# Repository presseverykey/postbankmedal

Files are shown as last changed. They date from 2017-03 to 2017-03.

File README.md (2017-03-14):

# POST /bank Hackathon Roadshow Medal

This repository contains hardware documentation (Eagle files and PDF) and firmware sources (C) for the medals given to winners at the POST /bank hackathon series 2016/2017 Grand Final.

The actual boards given out differ in two points:
- MCU ground connections (Pins 5 and 41) are missing on the board due to a PCB manufacturing error. They are manually routed using wire.
- Due to a worldwide supply shortage of TBD62083 drivers, the boards are populated with a TBD62003 chip (7 channels instead of 8). The remaining channel is populated with a 2N7000 NMOS on top of the TBD62003.

The board has pads for a resistive and a capacitive touch sensor, however, they are not used in the current firmware.

The firmware is based on the everykey SDK (see https://github.com/presseverykey/everykey-sdk for prerequisites, toolchain setup and more examples). Basically, an ARM GCC cross compiler and a firmware checksum tool is required. The MCU supports flashing via USB mass storage in ROM, so no additional flashing hardware is required. The firmware binary can be just copied over. To enable flashing mode, press the button while inserting the board to a USB port (add 0.5-1mm of cardboard or similar under the PCB for a stable connection). Some OSes will mount the drive directly, some require an additional reset. If required, a MCU reset can be triggered by connecting the corresponding pad of R5 to GND, e.g. using metal tweezers.

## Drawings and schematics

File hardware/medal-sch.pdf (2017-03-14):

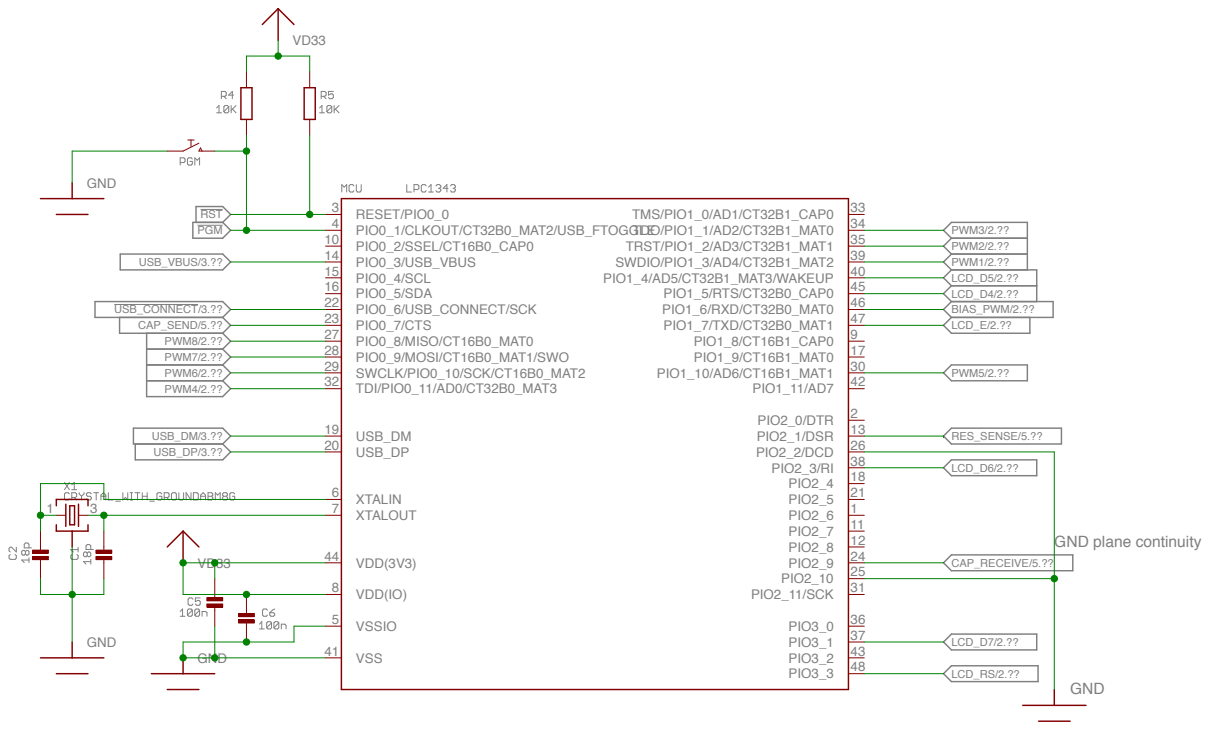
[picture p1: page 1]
GND; PIO2_6; PIO2_0/DTR; RESET/PIO0_0 3 PIO0_1/CLKOUT/CT32B0_MAT2/USB_FTOGGLE 4; VSSIO 5; XTALIN 6 XTALOUT 7; VDD(IO) 8; PIO1_8/CT16B1_CAP0; PIO0_2/SSEL/CT16B0_CAP0 10; PIO2_7; PIO2_8; PIO2_1/DSR; PIO0_3/USB_VBUS 14 PIO0_4/SCL 15 PIO0_5/SDA 16; PIO1_9/CT16B1_MAT0; PIO2_4; USB_DM 19 USB_DP 20; PIO2_5; PIO0_6/USB_CONNECT/SCK 22 PIO0_7/CTS 23; PIO2_9; PIO2_10; PIO2_2/DCD; PIO0_8/MISO/CT16B0_MAT0 27 PIO0_9/MOSI/CT16B0_MAT1/SWO 28; SWCLK/PIO0_10/SCK/CT16B0_MAT2 29; PIO1_10/AD6/CT16B1_MAT1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

GND plane continuity

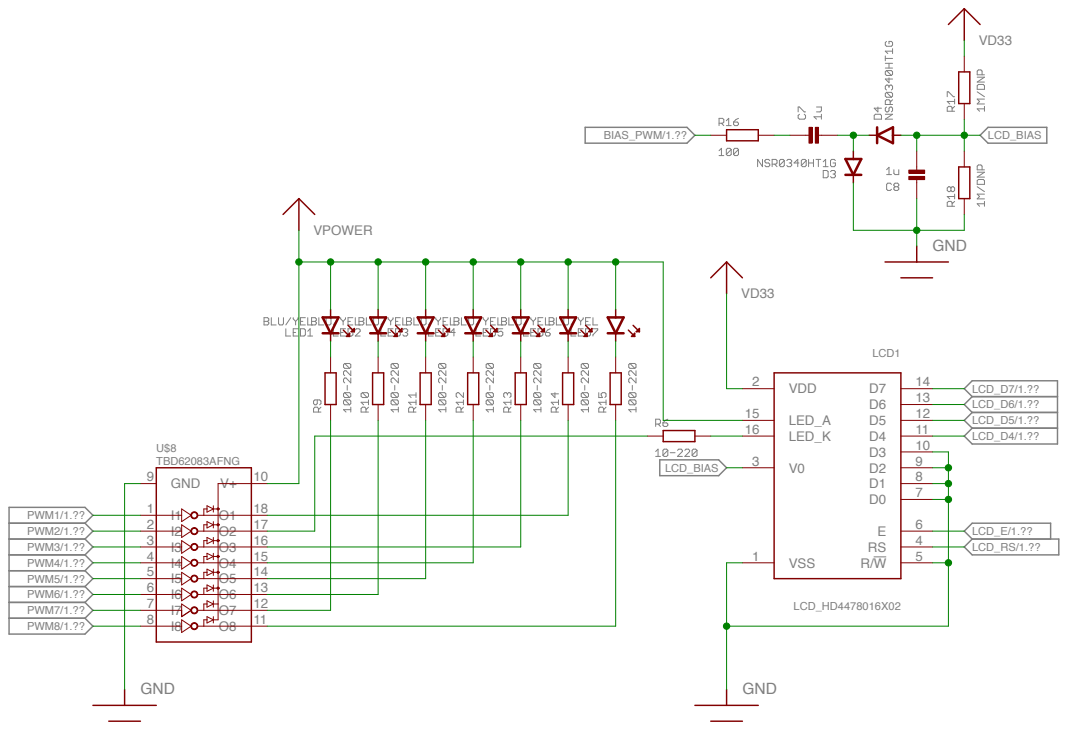
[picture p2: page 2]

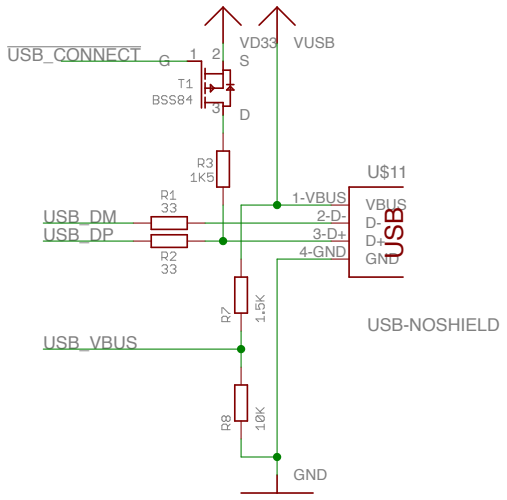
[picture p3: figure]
USB-NOSHIELD; GND; VBUS 1-VBUS D- 2-D- D+ 3-D+ GND 4-GND; VUSB; USB_DM USB_DP; USB_CONNECT; USB_VBUS; USB
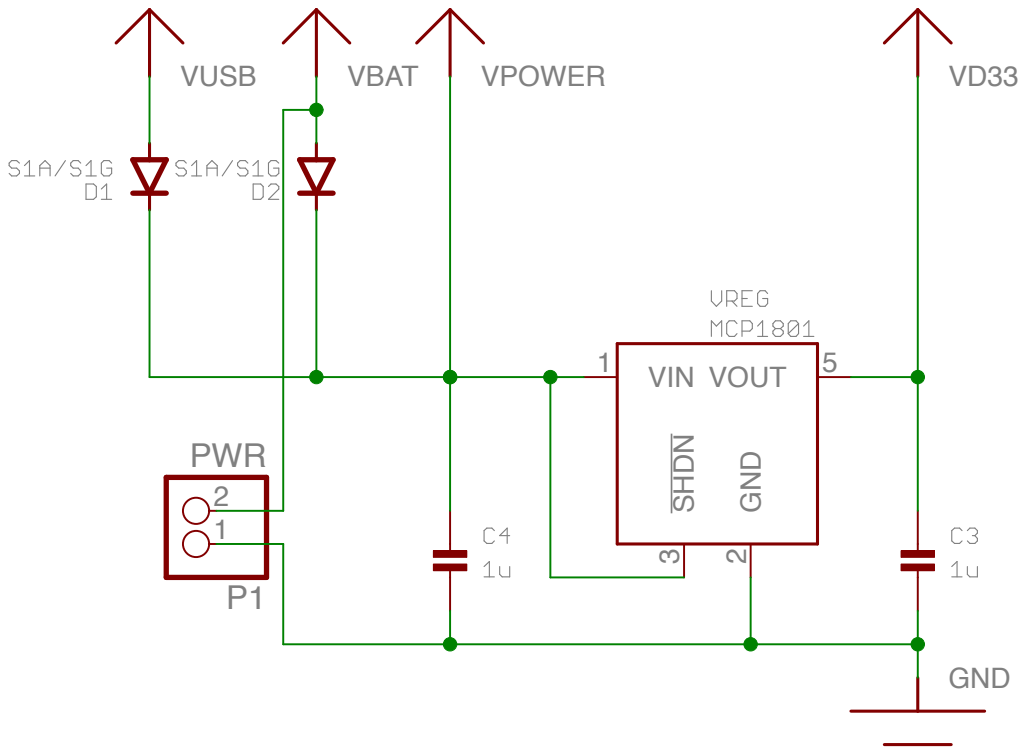
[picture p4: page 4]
PWR; VIN 1; VOUT; 5 GND 2 SHDN 3; GND; VUSB; VBAT; VPOWER

GND

VD33

CAP_SEND/1.??

CAP_RECEIVE/1.??

CAP_PAD

RES_SENSE/1.??

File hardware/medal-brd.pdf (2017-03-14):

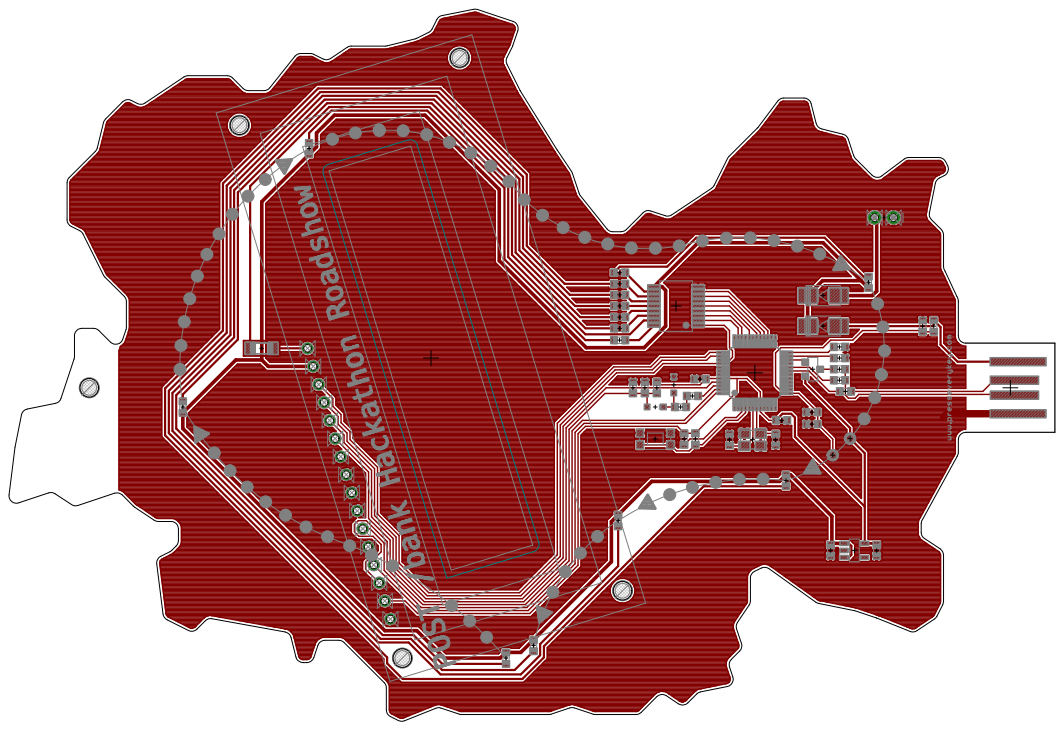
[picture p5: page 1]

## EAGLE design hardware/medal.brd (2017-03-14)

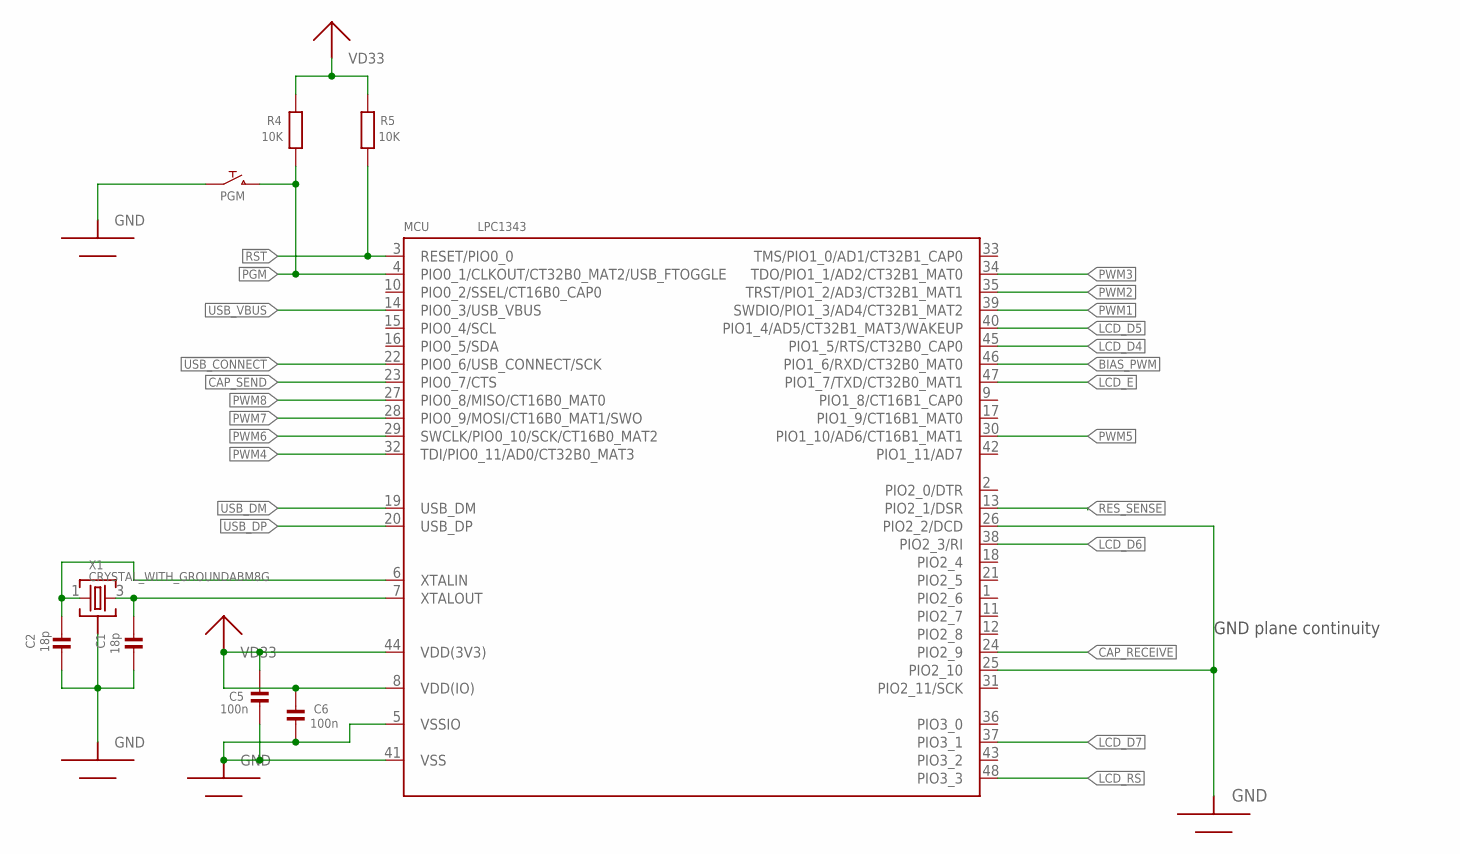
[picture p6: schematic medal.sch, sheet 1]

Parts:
C1, C2: 18p; 0603-NOSILK
C5, C6: 100n; 0603-NOSILK
MCU: LPC1343; QFP48-0.5-NOSILK
PGM: PUSHBUTTONKMR2XX-NOSILK; CK-KMR2-NOSILK
R4, R5: 10K; 0603-NOSILK
X1: CRYSTAL_WITH_GROUNDABM8G; ABM8G

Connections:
!PGM: MCU.4 (PIO0_1/CLKOUT/CT32B0_MAT2/USB_FTOGGLE), PGM.P$3 (2), PGM.P$4 (2), R4.1
!RST: MCU.3 (RESET/PIO0_0), R5.1
!USB_CONNECT: MCU.22 (PIO0_6/USB_CONNECT/SCK); also elsewhere on the board
BIAS_PWM: MCU.46 (PIO1_6/RXD/CT32B0_MAT0); also elsewhere on the board
CAP_RECEIVE: MCU.24 (PIO2_9); also elsewhere on the board
CAP_SEND: MCU.23 (PIO0_7/CTS); also elsewhere on the board
GND: C1.1, C2.1, C5.2, C6.2, MCU.5 (VSSIO), MCU.25 (PIO2_10), MCU.26 (PIO2_2/DCD), MCU.41 (VSS), PGM.P$1 (1), PGM.P$2 (1), X1.2 (GND), X1.4 (GND); also elsewhere on the board
LCD_D4: MCU.45 (PIO1_5/RTS/CT32B0_CAP0); also elsewhere on the board
LCD_D5: MCU.40 (PIO1_4/AD5/CT32B1_MAT3/WAKEUP); also elsewhere on the board
LCD_D6: MCU.38 (PIO2_3/RI); also elsewhere on the board
LCD_D7: MCU.37 (PIO3_1); also elsewhere on the board
LCD_E: MCU.47 (PIO1_7/TXD/CT32B0_MAT1); also elsewhere on the board
LCD_RS: MCU.48 (PIO3_3); also elsewhere on the board
unnamed: C2.2, MCU.6 (XTALIN), X1.1
unnamed: C1.2, MCU.7 (XTALOUT), X1.3 (2)
PWM1: MCU.39 (SWDIO/PIO1_3/AD4/CT32B1_MAT2); also elsewhere on the board
PWM2: MCU.35 (TRST/PIO1_2/AD3/CT32B1_MAT1); also elsewhere on the board
PWM3: MCU.34 (TDO/PIO1_1/AD2/CT32B1_MAT0); also elsewhere on the board
PWM4: MCU.32 (TDI/PIO0_11/AD0/CT32B0_MAT3); also elsewhere on the board
PWM5: MCU.30 (PIO1_10/AD6/CT16B1_MAT1); also elsewhere on the board
PWM6: MCU.29 (SWCLK/PIO0_10/SCK/CT16B0_MAT2); also elsewhere on the board
PWM7: MCU.28 (PIO0_9/MOSI/CT16B0_MAT1/SWO); also elsewhere on the board
PWM8: MCU.27 (PIO0_8/MISO/CT16B0_MAT0); also elsewhere on the board
RES_SENSE: MCU.13 (PIO2_1/DSR); also elsewhere on the board
USB_DM: MCU.19 (USB_DM); also elsewhere on the board
USB_DP: MCU.20 (USB_DP); also elsewhere on the board
USB_VBUS: MCU.14 (PIO0_3/USB_VBUS); also elsewhere on the board
VD33: C5.1, C6.1, MCU.8 (VDD(IO)), MCU.44 (VDD(3V3)), R4.2, R5.2; also elsewhere on the board

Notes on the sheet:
GND plane continuity

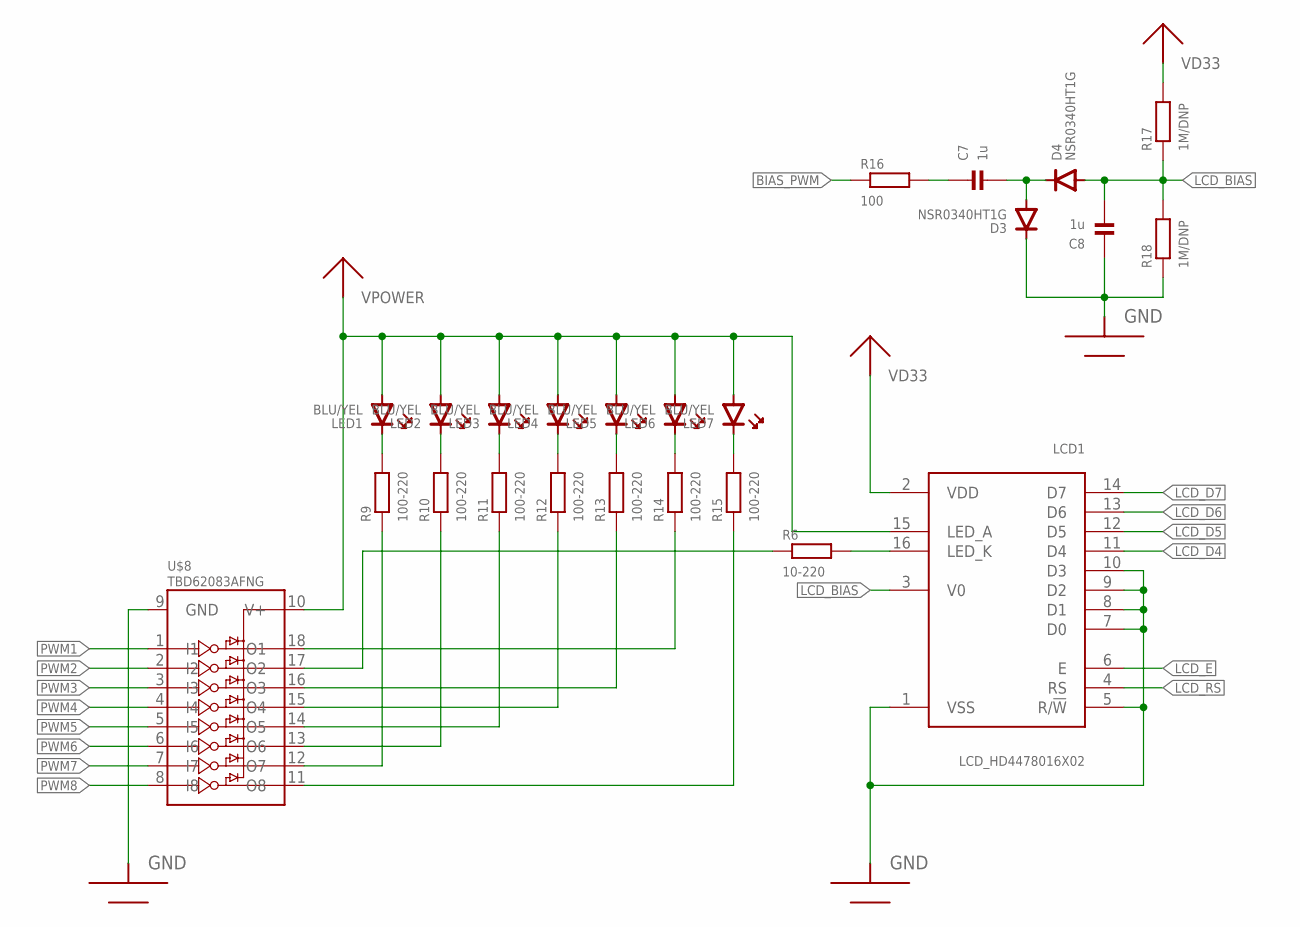
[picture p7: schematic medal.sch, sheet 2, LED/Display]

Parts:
C7, C8: 1u; 0603-NOSILK
D3, D4: NSR0340HT1G; SOD323R-NOPLACE
LCD1: LCD_HD4478016X02; LCD_16X02
LED1, LED2, LED3, LED4, LED5, LED6, LED7: BLU/YEL; 0603_POLAR
R6: 10-220; 1206-NOSILK
R9, R10, R11, R12, R13, R14, R15: 100-220; 0603-NOSILK
R16: 100; 0603-NOSILK
R17, R18: 1M/DNP; 0603-NOSILK
U$8: TBD62083AFNG; SSOP18-4.4-0.65-NOPLACE

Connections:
BIAS_PUMP: C7.2, D3.A (ANODE), D4.K (CATHODE)
BIAS_PWM: R16.1; also elsewhere on the board
BIAS_PWM_LIM: C7.1, R16.2
GND: C8.1, D3.K (CATHODE), LCD1.1 (VSS), LCD1.5 (R/!W), LCD1.7 (D0), LCD1.8 (D1), LCD1.9 (D2), LCD1.10 (D3), R18.1, U$8.9 (GND); also elsewhere on the board
LCD_BIAS: C8.2, D4.A (ANODE), LCD1.3 (V0), R17.1, R18.2
LCD_D4: LCD1.11 (D4); also elsewhere on the board
LCD_D5: LCD1.12 (D5); also elsewhere on the board
LCD_D6: LCD1.13 (D6); also elsewhere on the board
LCD_D7: LCD1.14 (D7); also elsewhere on the board
LCD_E: LCD1.6 (E); also elsewhere on the board
LCD_RS: LCD1.4 (RS); also elsewhere on the board
unnamed: R6.1, U$8.17 (O2)
unnamed: LCD1.16 (LED_K), R6.2
unnamed: R13.1, U$8.16 (O3)
unnamed: R10.1, U$8.13 (O6)
unnamed: LED1.K (CATHODE), R9.2
unnamed: LED2.K (CATHODE), R10.2
unnamed: LED3.K (CATHODE), R11.2
unnamed: LED4.K (CATHODE), R12.2
unnamed: LED5.K (CATHODE), R13.2
unnamed: LED6.K (CATHODE), R14.2
unnamed: LED7.K (CATHODE), R15.2
OC2: R9.1, U$8.12 (O7)
OC4: R11.1, U$8.14 (O5)
OC5: R12.1, U$8.15 (O4)
OC7: R14.1, U$8.18 (O1)
OC8: R15.1, U$8.11 (O8)
PWM1: U$8.1 (I1); also elsewhere on the board
PWM2: U$8.2 (I2); also elsewhere on the board
PWM3: U$8.3 (I3); also elsewhere on the board
PWM4: U$8.4 (I4); also elsewhere on the board
PWM5: U$8.5 (I5); also elsewhere on the board
PWM6: U$8.6 (I6); also elsewhere on the board
PWM7: U$8.7 (I7); also elsewhere on the board
PWM8: U$8.8 (I8); also elsewhere on the board
VD33: LCD1.2 (VDD), R17.2; also elsewhere on the board
VPOWER: LCD1.15 (LED_A), LED1.A (ANODE), LED2.A (ANODE), LED3.A (ANODE), LED4.A (ANODE), LED5.A (ANODE), LED6.A (ANODE), LED7.A (ANODE), U$8.10 (V+); also elsewhere on the board

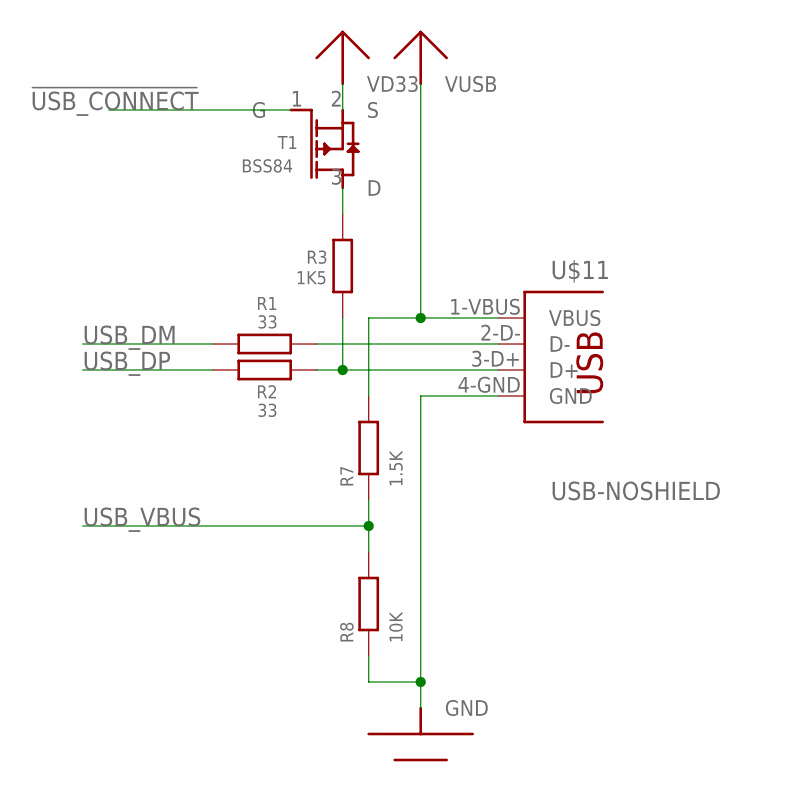
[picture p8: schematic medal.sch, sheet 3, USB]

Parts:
R1, R2: 33; 0603-NOSILK
R3: 1K5; 0603-NOSILK
R7: 1.5K; 0603-NOSILK
R8: 10K; 0603-NOSILK
T1: BSS84; SOT23-NOPLACE
U$11: USB-NOSHIELD; USB-A-PCB

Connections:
!USB_CONNECT: T1.1 (G); also elsewhere on the board
GND: R8.1, U$11.4-GND (GND); also elsewhere on the board
unnamed: R3.1, T1.3 (D)
USB_D+: R2.1, R3.2, U$11.3-D+ (D+)
USB_D-: R1.1, U$11.2-D- (D-)
USB_DM: R1.2; also elsewhere on the board
USB_DP: R2.2; also elsewhere on the board
USB_VBUS: R7.1, R8.2; also elsewhere on the board
VD33: T1.2 (S); also elsewhere on the board
VUSB: R7.2, U$11.1-VBUS (VBUS); also elsewhere on the board

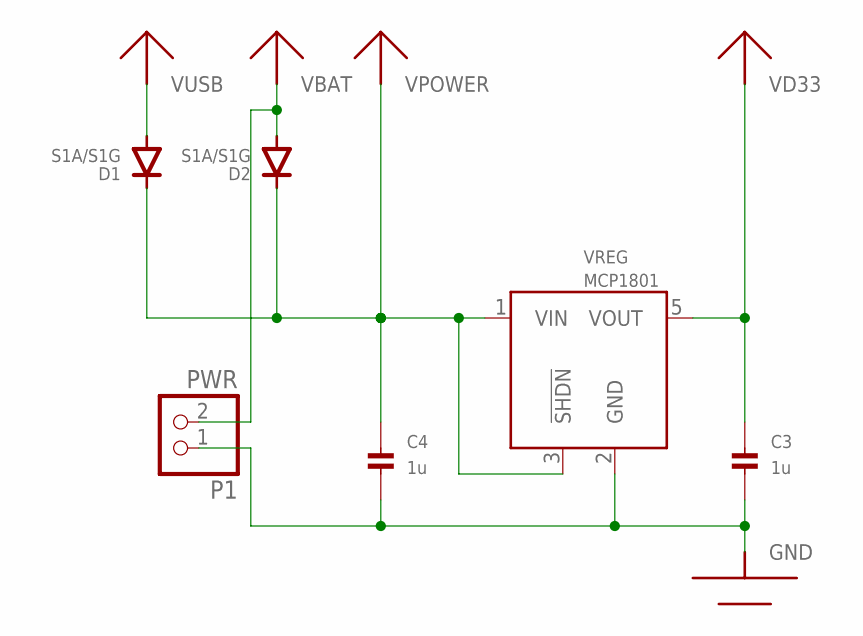
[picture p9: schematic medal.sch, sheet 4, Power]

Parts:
C3, C4: 1u; 0603-NOSILK
D1, D2: S1A/S1G; DSMA-NOPLACE
P1: PWR; 1X02_ROUND
VREG: MCP1801; SOT-23-5-NOSILK

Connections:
GND: C3.2, C4.2, P1.1, VREG.2 (GND); also elsewhere on the board
VBAT: D2.A (ANODE), P1.2
VD33: C3.1, VREG.5 (VOUT); also elsewhere on the board
VPOWER: C4.1, D1.C (CATHODE), D2.C (CATHODE), VREG.1 (VIN), VREG.3 (!SHDN); also elsewhere on the board
VUSB: D1.A (ANODE); also elsewhere on the board

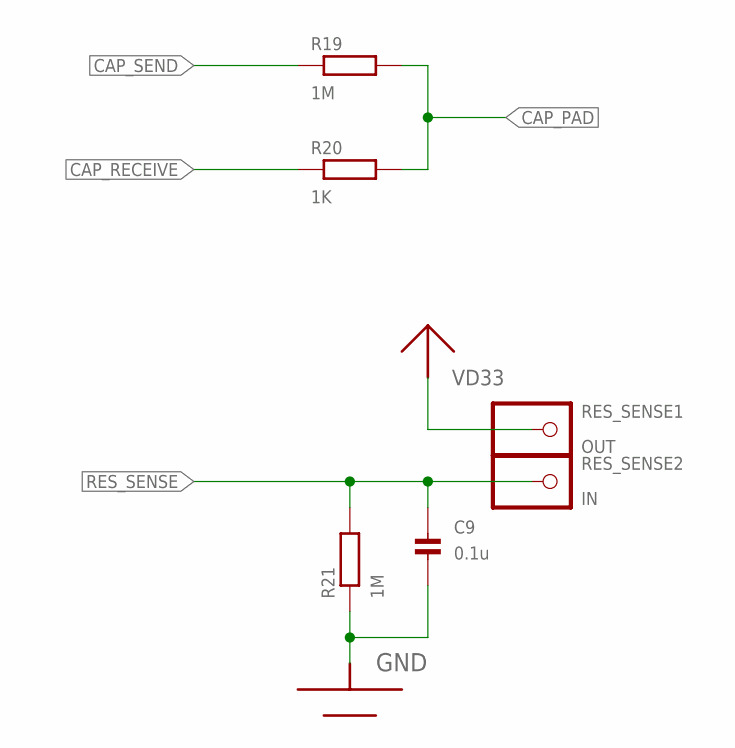
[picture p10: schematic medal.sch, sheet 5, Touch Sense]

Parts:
C9: 0.1u; 0603-NOSILK
R19, R21: 1M; 0603-NOSILK
R20: 1K; 0603-NOSILK
RES_SENSE1: OUT; 1X01_1MM_ROUND
RES_SENSE2: IN; 1X01_1MM_ROUND

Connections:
CAP_PAD: R19.2, R20.2
CAP_RECEIVE: R20.1; also elsewhere on the board
CAP_SEND: R19.1; also elsewhere on the board
GND: C9.2, R21.1; also elsewhere on the board
RES_SENSE: C9.1, R21.2, RES_SENSE2.P$2; also elsewhere on the board
VD33: RES_SENSE1.P$2; also elsewhere on the board

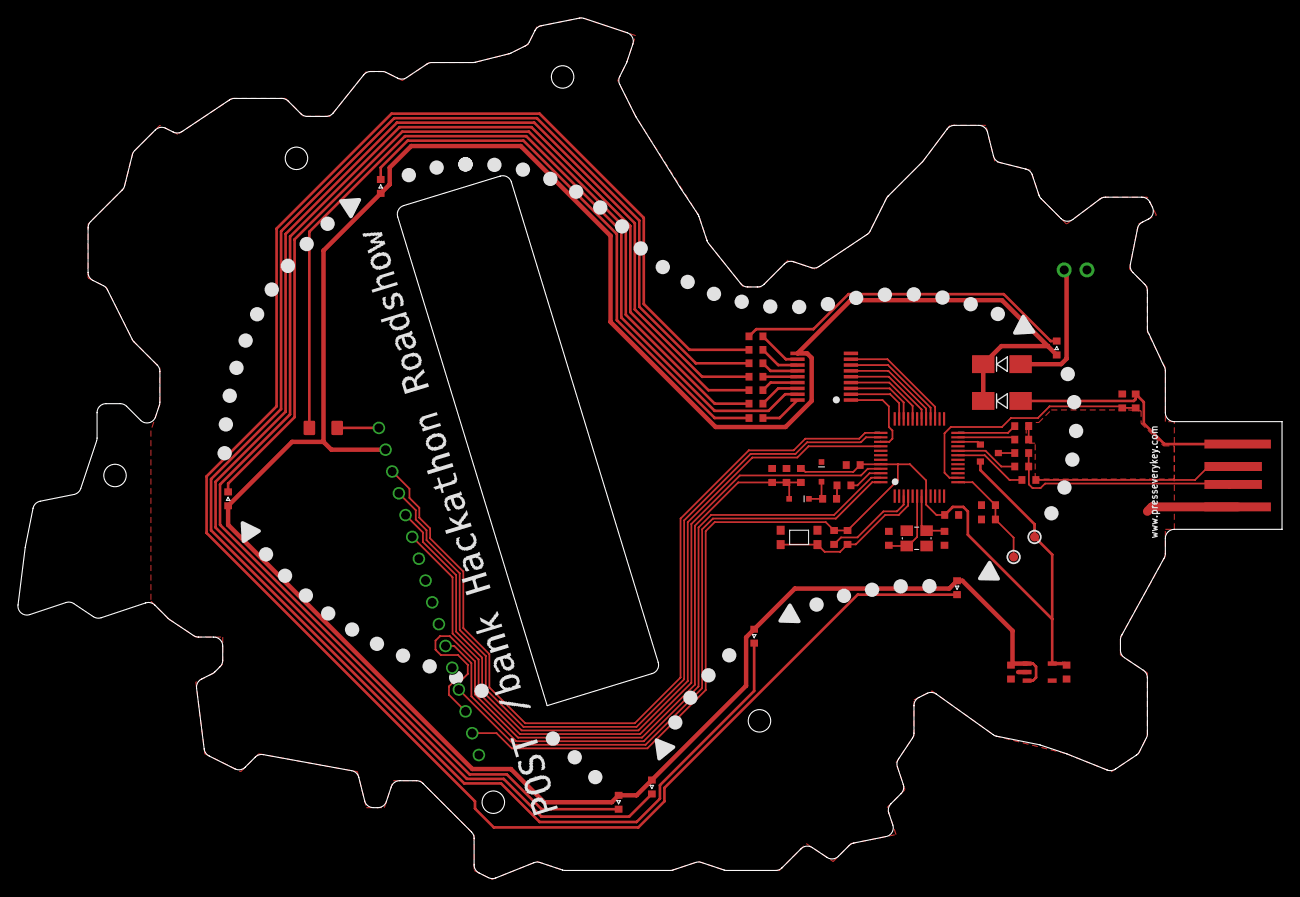
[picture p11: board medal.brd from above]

Board: 2 copper layers, 140.8 x 95.9 mm, 52 parts (0 on the bottom side), 54 nets.

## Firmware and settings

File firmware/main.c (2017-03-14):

#include "everykey/everykey.h"


typedef enum {
    GOTO = 0,        //arg1: LED mask, arg2: target value
    FADE,            //arg1: LED mask, arg2: target value, arg3: speed
    SPARKLE,         //arg1: LED mask
    SETTEXT,         //arg1: row, arg2: text index
    CLEARSCREEN,     //no args
    END,             //no args
    LOOP,            //no args
    TYPESTART,       //no args. Goes to line 1, turns on blinking cursor
    TYPE,            //arg2: char
    TYPEEND          //no args. Turns off blinking cursor
} COMMAND_ID;

typedef struct {
    uint16_t ticks;
    COMMAND_ID command;
    uint16_t arg1;
    uint8_t arg2;
    uint8_t arg3;
} Command;

const Command commands[] = {
    { 0, GOTO, 0b111111111, 0 },
    { 0, CLEARSCREEN, 0, 0, 0 },

    { 128, FADE, 0b000000011, 255, 2 }, //POST /bank fade up
//    {   0, SETTEXT, 0, 0, 0},           
    {   0, TYPESTART, 0, 0, 0 },
    { 200, TYPE, 0, 'P', 0 },
    {  30, TYPE, 0, 'O', 0 },
    {  30, TYPE, 0, 'S', 0 },
    {  30, TYPE, 0, 'T', 0 },
    {  30, TYPE, 0, ' ', 0 },
    {  30, TYPE, 0, '/', 0 },
    {  30, TYPE, 0, 'b', 0 },
    {  30, TYPE, 0, 'a', 0 },
    {  30, TYPE, 0, 'n', 0 },
    {  30, TYPE, 0, 'k', 0 },

    { 200, TYPEEND, 0, 0, 0 },     //blend to Hackathon Roadshow
    {   0, FADE, 0b000000001, 0, 2 },
    { 128, SETTEXT, 0, 1, 0},
    {   0, SETTEXT, 1, 2, 0},
    {   0, FADE, 0b000000001, 255, 2 },

    { 300, FADE, 0b000000011, 0, 2 },   //fade out
    
    { 128, SETTEXT, 0, 3, 0},           //Cologne
    {   0, SETTEXT, 1, 4, 0},
    {   0, FADE, 0b100000011, 255, 5 },
    { 200, FADE, 0b100000011, 0, 1 },

    { 128, SETTEXT, 0, 5, 0},           //Hamburg
    {   0, SETTEXT, 1, 6, 0},
    {   0, FADE, 0b010000011, 255, 5 },
    { 200, FADE, 0b010000011, 0, 1 },

    { 128, SETTEXT, 0, 7, 0},           //Berlin
    {   0, SETTEXT, 1, 8, 0},
    {   0, FADE, 0b001000011, 255, 5 },
    { 200, FADE, 0b001000011, 0, 1 },

    { 128, SETTEXT, 0, 9, 0},           //Munich
    {   0, SETTEXT, 1, 10, 0},
    {   0, FADE, 0b000100011, 255, 5 },
    { 200, FADE, 0b000100011, 0, 1 },

    { 128, SETTEXT, 0, 11, 0},          //Stuttgart
    {   0, SETTEXT, 1, 12, 0},
    {   0, FADE, 0b000010011, 255, 5 },
    { 200, FADE, 0b000010011, 0, 1 },

    { 128, SETTEXT, 0, 13, 0},          //Frankfurt
    {   0, SETTEXT, 1, 14, 0},
    {   0, FADE, 0b000001011, 255, 5 },
    { 200, FADE, 0b000001011, 0, 1 },

    { 128, SETTEXT, 0, 15, 0},          //Bonn
    {   0, SETTEXT, 1, 16, 0},
    {   0, FADE, 0b000000111, 255, 5 },
    { 200, FADE, 0b000000111, 0, 1 },

    { 128, SETTEXT, 0, 17, 0},          //Prize
    {   0, SETTEXT, 1, 18, 0},
    {   0, FADE, 0b000000011, 255, 2 },
    {   0, SPARKLE, 0b111111100, 0, 0 },
    { 200, FADE, 0b000000001, 150, 2},
    { 200, FADE, 0b000000001, 255, 2},
    { 200, FADE, 0b000000001, 150, 2},
    { 200, FADE, 0b000000001, 255, 2},
    { 200, FADE, 0b000000001, 150, 2},
    { 200, FADE, 0b000000001, 255, 2},
    { 200, FADE, 0b000000001, 150, 2},
    { 200, FADE, 0b000000001, 255, 2},
    { 200, FADE, 0b000000001, 150, 2},
    { 200, FADE, 0b000000001, 255, 2},
    { 200, FADE, 0b000000001, 150, 2},
    { 200, FADE, 0b000000001, 255, 2},
    { 200, FADE, 0b000000001, 150, 2},
    { 200, FADE, 0b000000001, 255, 2},
    { 200, FADE, 0b111111111, 0, 2 },

    { 200, LOOP, 0, 0, 0}
};

const char * const strings[] = {
    "POST /bank    ", //0
    "Hackathon     ", //1
    "Roadshow      ", //2
    "K\357ln          ", //3
    "3.-5.6.16     ", //4
    "Hamburg       ", //5
    "21.7.16       ", //6
    "Berlin        ", //7
    "30.9.-2.10.16 ", //8
    "M\365nchen       ", //9
    "20.10.16      ", //10
    "Stuttgart     ", //11
    "25.-27.11.16  ", //12
    "Frankfurt a.M.", //13
    "19.1.17       ", //14
    "Bonn          ", //15
    "17.3.17       ", //16
    "hack.institute", //17
    "sagt DANKE!   "  //18
};

const uint16_t gamma[] = {
    0,66,67,69,71,73,75,77,79,81,84,86,88,91,93,96,
    99,101,104,107,110,113,116,119,122,126,129,133,137,140,144,148,
    152,156,161,165,170,174,179,184,189,194,200,205,211,217,223,229,
    235,242,248,255,262,270,277,285,292,301,309,317,326,335,344,354,
    364,374,384,394,405,417,428,440,452,464,477,490,504,518,532,547,
    562,577,593,609,626,644,661,680,698,718,737,758,779,800,822,845,
    868,892,917,942,968,994,1022,1050,1079,1109,1139,1171,1203,1236,1270,1305,
    1341,1378,1416,1455,1495,1537,1579,1622,1667,1713,1760,1809,1859,1910,1963,2017,
    2072,2130,2188,2249,2311,2374,2440,2507,2576,2647,2720,2795,2872,2951,3033,3116,
    3202,3290,3381,3474,3570,3669,3770,3874,3980,4090,4203,4319,4438,4560,4686,4815,
    4948,5084,5224,5368,5516,5669,5825,5985,6150,6320,6494,6673,6857,7046,7241,7440,
    7645,7856,8073,8295,8524,8759,9000,9249,9504,9766,10035,10311,10596,10888,11188,11496,
    11813,12139,12474,12818,13171,13534,13907,14291,14685,15089,15505,15933,16372,16823,17287,17764,
    18254,18757,19274,19805,20351,20912,21489,22081,22690,23316,23958,24619,25298,25995,26712,27448,
    28205,28983,29782,30603,31446,32313,33204,34119,35060,36027,37020,38040,39089,40167,41274,42412,
    43581,44783,46018,47286,48590,49929,51306,52720,54174,55667,57202,58779,60400,62065,63776,65534
};


#define BUTTON_PORT 0
#define BUTTON_PIN 1

#define CT16B0_RESET_MAT 3
#define CT16B1_RESET_MAT 0
#define CT32B0_RESET_MAT 1
#define CT32B1_RESET_MAT 3

#define TIMER_PRESCALE 0
#define TIMER_PERIOD 65535
#define BIAS_VAL 2000

#define PWM1_PORT 0 //Circuit PWM4 - LED4 - Cologne
#define PWM1_PIN 11
#define PWM1_TIMER CT32B0
#define PWM1_MAT 3

#define PWM2_PORT 1 //Circuit PWM3 - LED5 - Hamburg
#define PWM2_PIN 1
#define PWM2_TIMER CT32B1
#define PWM2_MAT 0

#define PWM3_PORT 1 //Circuit PWM1 - LED6 - Berlin
#define PWM3_PIN 3
#define PWM3_TIMER CT32B1
#define PWM3_MAT 2

#define PWM4_PORT 0 //Circuit PWM8 - LED7 - Munich
#define PWM4_PIN 8
#define PWM4_TIMER CT16B0
#define PWM4_MAT 0

#define PWM5_PORT 0 //Circuit PWM7 - LED1 - Stuttgart
#define PWM5_PIN 9
#define PWM5_TIMER CT16B0
#define PWM5_MAT 1

#define PWM6_PORT 0 //Circuit PWM6 - LED2 - Frankfurt
#define PWM6_PIN 10
#define PWM6_TIMER CT16B0
#define PWM6_MAT 2

#define PWM7_PORT 1 //Circuit PWM5 - LED3 - Bonn
#define PWM7_PIN 10
#define PWM7_TIMER CT16B1
#define PWM7_MAT 1

#define BIASPWM_PORT 1
#define BIASPWM_PIN 6
#define BIASPWM_TIMER CT32B0
#define BIASPWM_MAT 0

#define LCDPWM_PORT 1
#define LCDPWM_PIN 2
#define LCDPWM_TIMER CT32B1
#define LCDPWM_MAT 1

#define LCD_RS_PORT 3
#define LCD_RS_PIN 3

#define LCD_E_PORT 1
#define LCD_E_PIN 7

#define LCD_D4_PORT 1
#define LCD_D4_PIN 5

#define LCD_D5_PORT 1
#define LCD_D5_PIN 4

#define LCD_D6_PORT 2
#define LCD_D6_PIN 3

#define LCD_D7_PORT 3
#define LCD_D7_PIN 1


/*   
 HD44780 write commands:
 
 D7  6  5  4  3  2  1  0
 
 0  0  0  0  0  0  0  1 : Clear display, home cursor
 0  0  0  0  0  0  1  - : Return cursor to home
 0  0  0  0  0  1  ID S : Set cursor move direction. ID=1: Increment cursor after write, S=Shift after write
 0  0  0  0  1  D  C  B : Enable display/cursor. D=1: Display on, C=1: Cursor on, B=1: Blink on
 0  0  0  1  SC RL -  - : Move cursor/shift display: SC=1:Shift display on, RL=1:shift right
 0  0  1  DL N  F  -  - : Set interface: DL=1:8 Bit (4 otherwise), N=1:2 lines (1 otherwise), F=1:5x10 font (5x7 otherwise)
 0  1  A  A  A  A  A  A : Move cursor to CGRAM. A:address
 1  A  A  A  A  A  A  A : Move cursor to display. A:address
 
 */

/** Simple busy wait. Should not be used from outside. Probably waits too long... */
void LCD_Wait_US(uint32_t us) {
    volatile uint32_t i = 30 * us;
    while (i > 0) i--;
}

/** writes one nibble. Should not be used from outside */
void LCD_Write4(bool rs, uint8_t value) {
    every_gpio_write(LCD_RS_PORT, LCD_RS_PIN, rs);
    every_gpio_write(LCD_D7_PORT, LCD_D7_PIN, value & 8);
    every_gpio_write(LCD_D6_PORT, LCD_D6_PIN, value & 4);
    every_gpio_write(LCD_D5_PORT, LCD_D5_PIN, value & 2);
    every_gpio_write(LCD_D4_PORT, LCD_D4_PIN, value & 1);
    
    every_gpio_write(LCD_E_PORT, LCD_E_PIN, true);
    LCD_Wait_US(1);
    
    every_gpio_write(LCD_E_PORT, LCD_E_PIN, false);
    LCD_Wait_US(1);
}

/** writes one byte using a 4 bit interface. Should not be used from outside */
void LCD_Write8(bool rs, uint8_t value) {
    LCD_Write4(rs, (value >> 4) & 0x0f);
    LCD_Write4(rs, value & 0x0f);
    LCD_Wait_US(60);
    if (!rs) LCD_Wait_US(2000);

}

/** writes a string onto screen, starting at the current cursor position. Chars 8-15 are also mapped to custom chars
 so that custom char 0 can be used even though 0 is end of string. */
void LCD_WriteString(const uint8_t* string) {
    int i=0;
    while (true) {
        uint8_t ch = string[i++];
        if (!ch) break;
        if ((ch >= 0x08) && (ch < 0x10)) ch-=8;
        LCD_Write8(true, ch);
    }
}

/** Clears the screen and homes the cursor */
void LCD_ClearScreen() {
    LCD_Write8(false, 0x01);    //clear screen, home cursor
}

/** Moves the cursor to the top left position. In contrast to GotoPosition, shifting is also reset. */
void LCD_Home() {
    LCD_Write8(false, 0x02);    //home cursor, reset shifts
}

/** turns the display and cursor features on or off. Does not modify memory contents. */
void LCD_EnableDisplay(bool screenOn, bool cursorOn, bool blinkOn) {
    LCD_Write8(false, 0x08 | (screenOn ? 0x04 : 0x00) | (cursorOn ? 0x02 : 0x00) | (blinkOn ? 0x01 : 0x00));    //display, cursor, blink on
}

/** sets the cursor to a given position. Note that this does not reflect funny memory maps found in some display configurations. 
 Two row displays should be fine */
void LCD_GotoPosition(uint8_t row, uint8_t col) {
    LCD_Write8(false, 0x80 | (row << 6) | col);
}

/** Defines a custom character (codes 0-7).
 Bitmap should be 8 bytes (rows, pixels right-aligned) even though sometimes only 7 are shown.
 Function will reset cursor position to home. */
void LCD_DefineChar(uint8_t charCode, const uint8_t bitmap[]) {
    LCD_Write8(false, 0x40 | (charCode << 3));
    int i;
    for (i=0; i<8; i++) {
        LCD_Write8(true, bitmap[i]);
    }
    LCD_Home();
}

/** initializes the pins and configures the display to a usable state */
void LCD_Init() {
    EVERY_GPIO_SET_FUNCTION(LCD_RS_PORT, LCD_RS_PIN, PIO, ADMODE_DIGITAL);
    every_gpio_set_dir(LCD_RS_PORT, LCD_RS_PIN, OUTPUT);
    every_gpio_write(LCD_RS_PORT, LCD_RS_PIN, 0);  //RS: 0 = command, 1 = data

    EVERY_GPIO_SET_FUNCTION(LCD_E_PORT, LCD_E_PIN, PIO, ADMODE_DIGITAL);
    every_gpio_set_dir(LCD_E_PORT, LCD_E_PIN, OUTPUT);
    every_gpio_write(LCD_E_PORT, LCD_E_PIN, 0);  //E: falling edge triggers transfer

    EVERY_GPIO_SET_FUNCTION(LCD_D4_PORT, LCD_D4_PIN, PIO, IOCON_IO_ADMODE_DIGITAL);
    every_gpio_set_dir(LCD_D4_PORT, LCD_D4_PIN, OUTPUT);
    every_gpio_write(LCD_D4_PORT, LCD_D4_PIN, 0);

    EVERY_GPIO_SET_FUNCTION(LCD_D5_PORT, LCD_D5_PIN, PIO, IOCON_IO_ADMODE_DIGITAL);
    every_gpio_set_dir(LCD_D5_PORT, LCD_D5_PIN, OUTPUT);
    every_gpio_write(LCD_D5_PORT, LCD_D5_PIN, 0);

    EVERY_GPIO_SET_FUNCTION(LCD_D6_PORT, LCD_D6_PIN, PIO, IOCON_IO_ADMODE_DIGITAL);
    every_gpio_set_dir(LCD_D6_PORT, LCD_D6_PIN, OUTPUT);
    every_gpio_write(LCD_D6_PORT, LCD_D6_PIN, 0);

    EVERY_GPIO_SET_FUNCTION(LCD_D7_PORT, LCD_D7_PIN, PIO, IOCON_IO_ADMODE_DIGITAL);
    every_gpio_set_dir(LCD_D7_PORT, LCD_D7_PIN, OUTPUT);
    every_gpio_write(LCD_D7_PORT, LCD_D7_PIN, 0);

    LCD_Wait_US(40000);
    
    LCD_Write4(false, 0x02);
    LCD_Wait_US(5000);

    LCD_Write8(false, 0x28);    //function set: 4 bit, 2 lines, 5x7 font
    LCD_Write8(false, 0x06);    //entry mode: Move cursor
    LCD_EnableDisplay(true, false, false);
    LCD_ClearScreen();
}

uint16_t timerValues[9];    //LED1-7, LCD BG, LCD BIAS

void PWM_UpdateValues() {
    Timer_SetMatchValue(PWM1_TIMER, PWM1_MAT, timerValues[0]);
    Timer_SetMatchValue(PWM2_TIMER, PWM2_MAT, timerValues[1]);
    Timer_SetMatchValue(PWM3_TIMER, PWM3_MAT, timerValues[2]);
    Timer_SetMatchValue(PWM4_TIMER, PWM4_MAT, timerValues[3]);
    Timer_SetMatchValue(PWM5_TIMER, PWM5_MAT, timerValues[4]);
    Timer_SetMatchValue(PWM6_TIMER, PWM6_MAT, timerValues[5]);
    Timer_SetMatchValue(PWM7_TIMER, PWM7_MAT, timerValues[6]);
    Timer_SetMatchValue(LCDPWM_TIMER, LCDPWM_MAT, timerValues[7]);
    Timer_SetMatchValue(BIASPWM_TIMER, BIASPWM_MAT, timerValues[8]);
}

void PWM_Init() {
    Timer_Enable(CT16B0, true);
    Timer_Enable(CT16B1, true);
    Timer_Enable(CT32B0, true);
    Timer_Enable(CT32B1, true);
    Timer_SetPrescale(CT16B0, TIMER_PRESCALE);
    Timer_SetPrescale(CT16B1, TIMER_PRESCALE);
    Timer_SetPrescale(CT32B0, TIMER_PRESCALE);
    Timer_SetPrescale(CT32B1, TIMER_PRESCALE);
    Timer_SetMatchValue(CT16B0, CT16B0_RESET_MAT, TIMER_PERIOD);
    Timer_SetMatchValue(CT16B1, CT16B1_RESET_MAT, TIMER_PERIOD);
    Timer_SetMatchValue(CT32B0, CT32B0_RESET_MAT, TIMER_PERIOD);
    Timer_SetMatchValue(CT32B1, CT32B1_RESET_MAT, TIMER_PERIOD);
    Timer_SetMatchBehaviour(CT16B0, CT16B0_RESET_MAT, TIMER_MATCH_RESET);
    Timer_SetMatchBehaviour(CT16B1, CT16B1_RESET_MAT, TIMER_MATCH_RESET);
    Timer_SetMatchBehaviour(CT32B0, CT32B0_RESET_MAT, TIMER_MATCH_RESET);
    Timer_SetMatchBehaviour(CT32B1, CT32B1_RESET_MAT, TIMER_MATCH_RESET);

    Timer_EnablePWM(PWM1_TIMER, PWM1_MAT, true);
    Timer_EnablePWM(PWM2_TIMER, PWM2_MAT, true);
    Timer_EnablePWM(PWM3_TIMER, PWM3_MAT, true);
    Timer_EnablePWM(PWM4_TIMER, PWM4_MAT, true);
    Timer_EnablePWM(PWM5_TIMER, PWM5_MAT, true);
    Timer_EnablePWM(PWM6_TIMER, PWM6_MAT, true);
    Timer_EnablePWM(PWM7_TIMER, PWM7_MAT, true);
    Timer_EnablePWM(LCDPWM_TIMER, LCDPWM_MAT, true);
    Timer_EnablePWM(BIASPWM_TIMER, BIASPWM_MAT, true);

    EVERY_GPIO_SET_FUNCTION(PWM1_PORT, PWM1_PIN, TMR, ADMODE_DIGITAL);
    EVERY_GPIO_SET_FUNCTION(PWM2_PORT, PWM2_PIN, TMR, ADMODE_DIGITAL);
    EVERY_GPIO_SET_FUNCTION(PWM3_PORT, PWM3_PIN, TMR, ADMODE_DIGITAL);
    EVERY_GPIO_SET_FUNCTION(PWM4_PORT, PWM4_PIN, TMR, ADMODE_DIGITAL);
    EVERY_GPIO_SET_FUNCTION(PWM5_PORT, PWM5_PIN, TMR, ADMODE_DIGITAL);
    EVERY_GPIO_SET_FUNCTION(PWM6_PORT, PWM6_PIN, TMR, ADMODE_DIGITAL);
    EVERY_GPIO_SET_FUNCTION(PWM7_PORT, PWM7_PIN, TMR, ADMODE_DIGITAL);
    EVERY_GPIO_SET_FUNCTION(LCDPWM_PORT, LCDPWM_PIN, TMR, ADMODE_DIGITAL);
    EVERY_GPIO_SET_FUNCTION(BIASPWM_PORT, BIASPWM_PIN, TMR, ADMODE_DIGITAL);

    for (int i=0; i<8; i++) {
        timerValues[i] = 65535;
    }
    timerValues[8] = BIAS_VAL;
    PWM_UpdateValues();

    Timer_Reset(CT16B0);
    Timer_Reset(CT16B1);
    Timer_Reset(CT32B0);
    Timer_Reset(CT32B1);
    Timer_Start(CT16B0);
    Timer_Start(CT16B1);
    Timer_Start(CT32B0);
    Timer_Start(CT32B1);
}

void main(void) {

    EVERY_GPIO_SET_FUNCTION(BUTTON_PORT, BUTTON_PIN, PIO, ADMODE_DIGITAL);
    every_gpio_set_dir(BUTTON_PORT, BUTTON_PIN, INPUT);
    EVERY_GPIO_SET_PULL(BUTTON_PORT,BUTTON_PIN, PULL_UP);

    PWM_Init();
    LCD_Init();
    
    const uint8_t char0[] = {0x10,0x10,0x10,0x10,0x10,0x10,0x10,0x10};
    const uint8_t char1[] = {0x18,0x18,0x18,0x18,0x18,0x18,0x18,0x18};
    const uint8_t char2[] = {0x1c,0x1c,0x1c,0x1c,0x1c,0x1c,0x1c,0x1c};
    const uint8_t char3[] = {0x1e,0x1e,0x1e,0x1e,0x1e,0x1e,0x1e,0x1e};
    const uint8_t char4[] = {0x1f,0x1f,0x1f,0x1f,0x1f,0x1f,0x1f,0x1f};
    LCD_DefineChar(0,char0);
    LCD_DefineChar(1,char1);
    LCD_DefineChar(2,char2);
    LCD_DefineChar(3,char3);
    LCD_DefineChar(4,char4);

    SYSCON_StartSystick_10ms();
}

uint32_t ticks = 0;
uint32_t totalTicks = 0;
uint32_t commandIdx = 0;
bool running = true;
uint8_t ledValue[9];
uint8_t ledTarget[9];
uint8_t ledSpeed[9];    //ff = sparkle

void parseCommand() {
    if (!running) { //not running: check start condition
        if (!every_gpio_read(BUTTON_PORT, BUTTON_PIN)) {
            ticks = 0;
            commandIdx = 0;
            running = true;
        } else {
            return;
        }
    }
    ticks++;
    totalTicks++;
    uint16_t nextTick = commands[commandIdx].ticks;
    while (ticks >= nextTick) {
        COMMAND_ID cmd = commands[commandIdx].command;
        uint16_t arg1 = commands[commandIdx].arg1;
        uint8_t arg2 = commands[commandIdx].arg2;
        uint8_t arg3 = commands[commandIdx].arg3;
        switch (cmd) {
            case GOTO:
                for (int i=0; i<9; i++) {
                    if (arg1 & (0x100 >> i)) {
                        ledValue[i] = arg2;
                        ledTarget[i] = arg2;
                        ledSpeed[i] = 0;
                    }
                }
                break;
            case FADE:
                for (int i=0; i<9; i++) {
                    if (arg1 & (0x100 >> i)) {
                        ledTarget[i] = arg2;
                        ledSpeed[i] = arg3;
                    }
                }
                break;
            case SPARKLE:
                for (int i=0; i<9; i++) {
                    if (arg1 & (0x100 >> i)) {
                        ledSpeed[i] = 0xff;
                    }
                }
                break;
            case SETTEXT:
                LCD_GotoPosition(arg1,1);
                LCD_WriteString(strings[arg2]);
                break;
            case CLEARSCREEN:
                LCD_ClearScreen();
                break;
            case END:
                running = false;
                break;
            case LOOP:
                commandIdx = 0;
                ticks = 0;
                return;
                break;
            case TYPESTART:
                LCD_EnableDisplay(true, true, true);
                LCD_GotoPosition(0,1);
                break;
            case TYPE:
                LCD_Write8(true, arg2);
                break;
            case TYPEEND:
                LCD_EnableDisplay(true, false, false);
                break;

        }   
        commandIdx++;
        ticks = 0;
        if (!running) break;
        nextTick = commands[commandIdx].ticks;
    }
}

void animateLEDs() {
    for (int i=0; i<9; i++) {
        uint8_t speed = ledSpeed[i];
        if (speed == 0xff) {                      //sparkle
            uint8_t val = 255 - 2 * (totalTicks & 0x7f); //ramp down
            val += 36*i;  //shift LEDs
            ledValue[i] = val;
        } else if (ledTarget[i] > ledValue[i]) {  //fade up
            uint8_t delta = ledTarget[i] - ledValue[i];
            if (speed <= delta) {
                delta = speed;
            }
            ledValue[i] += delta;
        } else if (ledTarget[i] < ledValue[i]) {  //fade down
            uint8_t delta = ledValue[i] - ledTarget[i];
            if (speed <= delta) {
                delta = speed;
            }
            ledValue[i] -= delta;
        }
    }
    for (int i=0; i<8; i++) {
        timerValues[i] = 65534 - gamma[ledValue[i]];
    }
    timerValues[8] = 8 * ledValue[8];
    PWM_UpdateValues();
}

void systick() {
    parseCommand();
    animateLEDs();


    // static uint32_t counter;
    // counter++;
    // uint32_t phase = counter & 0x7f;
    // uint32_t stage = counter >> 7;

    //     for (int i=0; i<8; i++) {
    //         timerValues[i] = (counter << 8) + 8192 * i;
    //     }
    //     PWM_UpdateValues();

    // if (phase == 0) {
    //     LCD_Home();
    //     LCD_WriteString("Hello");
    //     LCD_GotoPosition(1,0);
    //     LCD_WriteString("World");
    // }       
}
